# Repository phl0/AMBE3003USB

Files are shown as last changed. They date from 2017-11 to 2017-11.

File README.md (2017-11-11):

# AMBE3003USB

This is a homebrew evaluation board for AMBE-3000 and AMBE-3003 Chips. It can be used as a replacement for USB-3003 devices to work as a transcoder for [XLX](https://github.com/LX3JL/xlxd) reflectors. This board is supported by the AMBEd daemon from version 1.2 onwards.

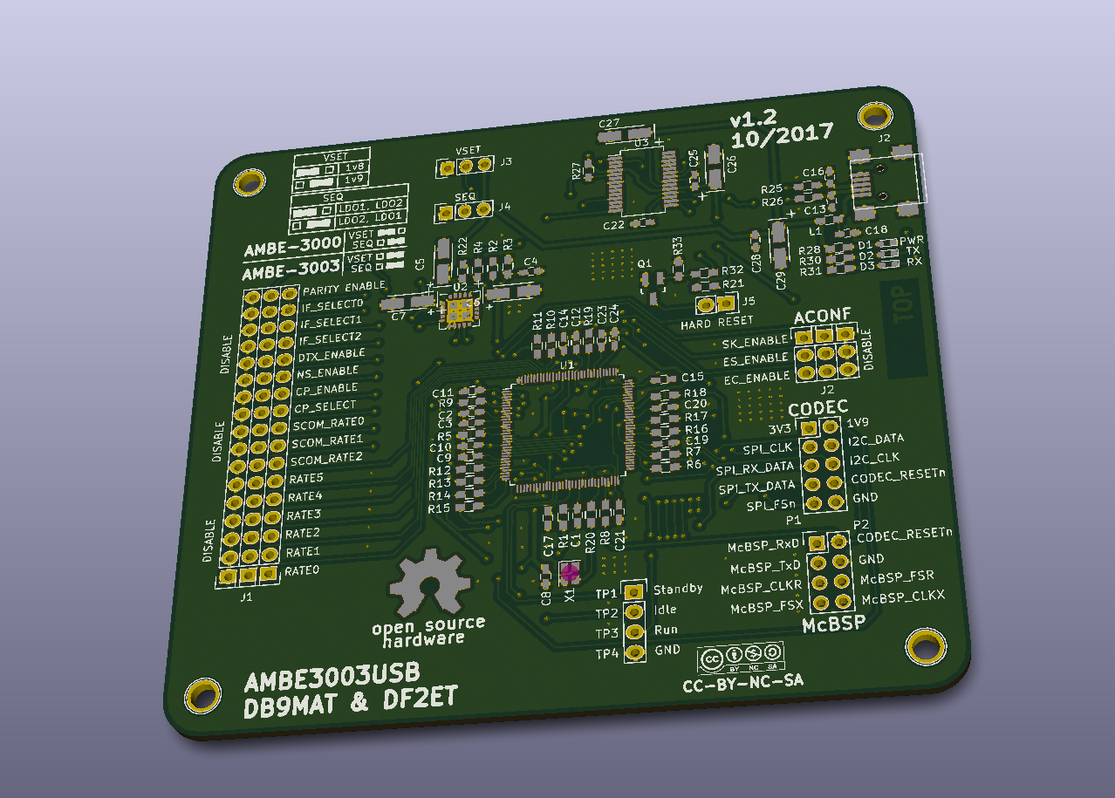
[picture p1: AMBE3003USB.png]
PCB


## Version 1.0

This is the initial version. Apparently it has two errors: The power supply is faulty due to R42 being to small in value. Bypassing the resistor works basically. The 1v9 rail draws to much power resulting in U5 running hot. 
The second issue is that this revision does not support hardware reset of the AMBE-3003 CPU. Soft reset does not work 100% reliably. In this case only un- and re-plugging the device works.

This is the link to the [Mouser project](https://www.mouser.com/ProjectManager/ProjectDetail.aspx?AccessID=42f49e97ec) shopping cart.

**This version is not recommended for (re-)production!**

## Version 1.1

The power supply has been redesigned. An additional transistor has been added to allow for a hardware reset using the DTR pin of the FT-232RL. This needs code changes in the XLX code. Additionally there have been added some more pins to the pin header that allow for configuring parity for AMBE-3000 chips by jumper.

Testing this version revealed an issue with missing pull-up resistor on the PWREN signal. That results in the voltage regulator not beeing activated. Quick fix is to add a 10k SMD resistor from bottom pin of R4 to anode of C5 (5v0). This is going to be fixed in revision 1.2.

This is the link to the [Mouser project](https://www.mouser.com/ProjectManager/ProjectDetail.aspx?AccessID=05fa8acc46) shopping cart.

**This version is not recommended for (re-)production!**

## Version 1.2

A 10k resistor (R22) was added to the schematics and board layout. 

This is the link to the [Mouser project](https://www.mouser.com/ProjectManager/ProjectDetail.aspx?AccessID=9071144aec) shopping cart.

**This version has not been tested yet. Use at your own risk.**

# Usage

## Flashing FT232

After building the board you have to flash the onboard FT-232 USB converter. The AMBEd expects to find this device with product ID "DF2ET-3003". The product ID can be flashed with the original FTprog by FTDI or using [ft232r_prog](http://rtr.ca/ft232r/) (command is ./ft232r_prog --product "DF2ET-3003").

## Setting Jumpers

* VSET has to be set to 1v9 for an AMBE-3003 chip (1v8 for AMBE-3000).
* SEQ needs to be LDO2, LDO1
* PARITY_ENABLE is ignored by an AMBE-3003 (disabled for AMBE-3000)
* IF_SELECT has to be set to UART (being IF_SELECT0 and IF_SELECT2 enabled, IF_SELECT1 disabled)
* DTX_ENABLE disabled
* NS_ENABLE disabled
* CP_ENABLE disabled
* CP_SELECT disabled
* SCOM_RATE has to be configured for 921,600 bit/s (which is SCOM_RATE0 and SCOM_RATE2 enabled, SCOM_RATE1 disabled)
* RATE settings are ignored in UART mode. No need for jumpers though

* HARD_RESET can be enabled by setting J5. Otherwise the code relies on a software reset only

* SK_ENABLE not used by AMBE-3003
* ES_ENABLE not used by AMBE-3003
* EC_ENABLE not used by AMBE-3003

## Drivers

If using in combination with XLX/AMBEd make sure that the operating system does not load the commonly used ftdi_sio kernel module to provide an USB-serial interface. The AMBEd makes use of the ft2xx direct access driver by FTDI with does not work if the kernel module is loaded. Hints on how this can be accomplished can be found in my [Blog](https://www.florian-wolters.de/blog/2017/08/18/excluding-ft-232-from-ftdi-sio-driver/).

# Contributors

This is the list of contributors. Thank you for your additions:

* Mathis, DB9MAT

# License

This project is released under the Creative Commons Attribution-NonCommercial-ShareAlike 3.0 (CC-BY-NC-SA 3.0, https://creativecommons.org/licenses/by-nc-sa/3.0/) license. You may edit and share it as you like, as long as credit is given and the license is not changed. You can build as many boards for you and your friends as you like and you can even sell it to them to cover your costs, **however it is strictly forbidden to turn this into a commercial product! You are not allowed to build and sell these boards for profit!**

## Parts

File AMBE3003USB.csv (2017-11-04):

Refs | Value | Footprint | QTY | MFR | MPN | SPR | SPN
C28;C25;C23;C20;C17;C14;C11;C9;C24;C21;C19;C15;C12;C10;C22 | 100n | Capacitors_SMD:C_0603_HandSoldering | 15 | Murata Electronics | GRM188R70J104KA01D | Mouser | 81-GRM188R70J104KA1D
C18;C1;C8;C4 | 10n | Capacitors_SMD:C_0603_HandSoldering | 4 | Murata Electronics | GRM188R70J103KA01D | Mouser | 81-GRM188R70J103KA1D
C3;C2 | 10u | Capacitors_SMD:C_0603_HandSoldering | 2 | Murata Electronics | GRM188R60J106ME47D | Mouser | 81-GRM188R60J106ME47
C13;C16 | 47p | Capacitors_SMD:C_0603_HandSoldering | 2 | AVX | 06036A470JAT2A | Mouser | 581-06036A470JAT2A
C5;C7;C6 | 10u | Capacitors_Tantalum_SMD:TantalC_SizeA_EIA-3216_HandSoldering | 3 | KEMET | T495A106K016ATE1K7 | Mouser | 80-T495A106K016AT
C26;C27 | 1u | Capacitors_Tantalum_SMD:TantalC_SizeA_EIA-3216_HandSoldering | 2 | KEMET | T495A105K020ATE3K0 | Mouser | 80-T495A105K20ATE3K0
C29 | 4u7 | Capacitors_Tantalum_SMD:TantalC_SizeA_EIA-3216_HandSoldering | 1 | KEMET | T495A475K020ATE1K8 | Mouser | 80-T495A475K20ATE1K8
J2 | USB_OTG | Connect:USB_Mini-B | 1 | Molex | 67503-1020 | Mouser | 538-67503-1020
U2 | TPS75005RGW_wPin21 | Housings_DFN_QFN:QFN-20-1EP_5x5mm_Pitch0.65mm | 1 | Texas Instruments | TPS75005RGWT | Mouser | 595-TPS75005RGWT
U1 | AMBE3003 | Housings_QFP:TQFP-128_14x14mm_Pitch0.4mm | 1 | DVSI | AMBE-3003
U3 | FT232RL | Housings_SSOP:SSOP-28_5.3x10.2mm_Pitch0.65mm | 1 | FTDI | FT232RL-REEL | Mouser | 895-FT232RL
L1 | 100MHz | Inductors_SMD:L_0603_HandSoldering | 1 | Murata Electronics | BLM18KG471BH1D | Mouser | 81-BLM18KG471BH1D
D1 | green | LEDs:LED_0603 | 1 | Wurth Electronics | 150060VS75000 | Mouser | 710-150060VS75000
D3 | red | LEDs:LED_0603 | 1 | Wurth Electronics | 150060SS75000 | Mouser | 710-150060SS75000
D2 | yellow | LEDs:LED_0603 | 1 | Wurth Electronics | 150060YS75000 | Mouser | 710-150060YS75000
X1 | 29.4912 | Oscillators:Oscillator_SMD_SeikoEpson_SG210-4pin_2.5x2.0mm | 1 | Epson Timing | SG-210STF 29.4912ML3 | Mouser | 732-SG210STF29.491L3
P5 | HARD RESET | Pin_Headers:Pin_Header_Straight_1x02 | 1 | Harwin | M20-9990246 | Mouser | 855-M20-9990246
P7 | 3v3 | Pin_Headers:Pin_Header_Straight_1x03 | 1 | Harwin | M20-9990346 | Mouser | 855-M20-9990346
P8 | ACONF | Pin_Headers:Pin_Header_Straight_1x03 | 1 | Harwin | M20-9990346 | Mouser | 855-M20-9990346
P9 | GND | Pin_Headers:Pin_Header_Straight_1x03 | 1 | Harwin | M20-9990346 | Mouser | 855-M20-9990346
P6 | SEQ | Pin_Headers:Pin_Header_Straight_1x03 | 1 | Harwin | M20-9990346 | Mouser | 855-M20-9990346
P4 | VSET | Pin_Headers:Pin_Header_Straight_1x03 | 1 | Harwin | M20-9990346 | Mouser | 855-M20-9990346
TP1 | Testpoints | Pin_Headers:Pin_Header_Straight_1x04 | 1 | Harwin | M20-9990446 | Mouser | 855-M20-9990446
P3 | 3v3 | Pin_Headers:Pin_Header_Straight_1x17 | 1 | Harwin | M20-9991746 | Mouser | 855-M20-9991746
P2 | Config | Pin_Headers:Pin_Header_Straight_1x17 | 1 | Harwin | M20-9991746 | Mouser | 855-M20-9991746
P1 | GND | Pin_Headers:Pin_Header_Straight_1x17 | 1 | Harwin | M20-9991746 | Mouser | 855-M20-9991746
J1 | McBSP | Pin_Headers:Pin_Header_Straight_2x04 | 1 | Harwin | M20-9980445 | Mouser | 855-M20-9980445
J4 | CODEC | Pin_Headers:Pin_Header_Straight_2x05 | 1 | Harwin | M20-9980545 | Mouser | 855-M20-9980545
R12;R13;R14;R15;R16;R17;R18;R6;R7;R8;R9;R10;R11;R19 | 0R | Resistors_SMD:R_0603_HandSoldering | 14 | Yageo | RC0603FR-070RL | Mouser | 603-RC0603FR-070RL
R21;R3;R33;R22 | 10k | Resistors_SMD:R_0603_HandSoldering | 4 | Yageo | RC0603FR-0710KL | Mouser | 603-RC0603FR-0710KL
R32 | 1k | Resistors_SMD:R_0603_HandSoldering | 1 | Yageo | RC0603FR-071KL | Mouser | 603-RC0603FR-071KL
R5;R27;R4 | 24k | Resistors_SMD:R_0603_HandSoldering | 3 | Yageo | RC0603FR-0724KL | Mouser | 603-RC0603FR-0724KL
R25;R26 | 27 | Resistors_SMD:R_0603_HandSoldering | 2 | Yageo | RC0603FR-0727RL | Mouser | 603-RC0603FR-0727RL
R30;R31;R28 | 270 | Resistors_SMD:R_0603_HandSoldering | 3 | Yageo | RC0603FR-07270RL | Mouser | 603-RC0603FR-07270RL
R2 | 3k74 | Resistors_SMD:R_0603_HandSoldering | 1 | Yageo | RC0603FR-073K74L | Mouser | 603-RC0603FR-073K74L
R1;R20 | 5.1 | Resistors_SMD:R_0603_HandSoldering | 2 | Yageo | RC0603FR-075R11L | Mouser | 603-RC0603FR-075R11L
Q1 | BC847 | TO_SOT_Packages_SMD:SOT-23_Handsoldering | 1 | ON Semiconductor | BC847BLT1G | Mouser | 863-BC847BLT1G

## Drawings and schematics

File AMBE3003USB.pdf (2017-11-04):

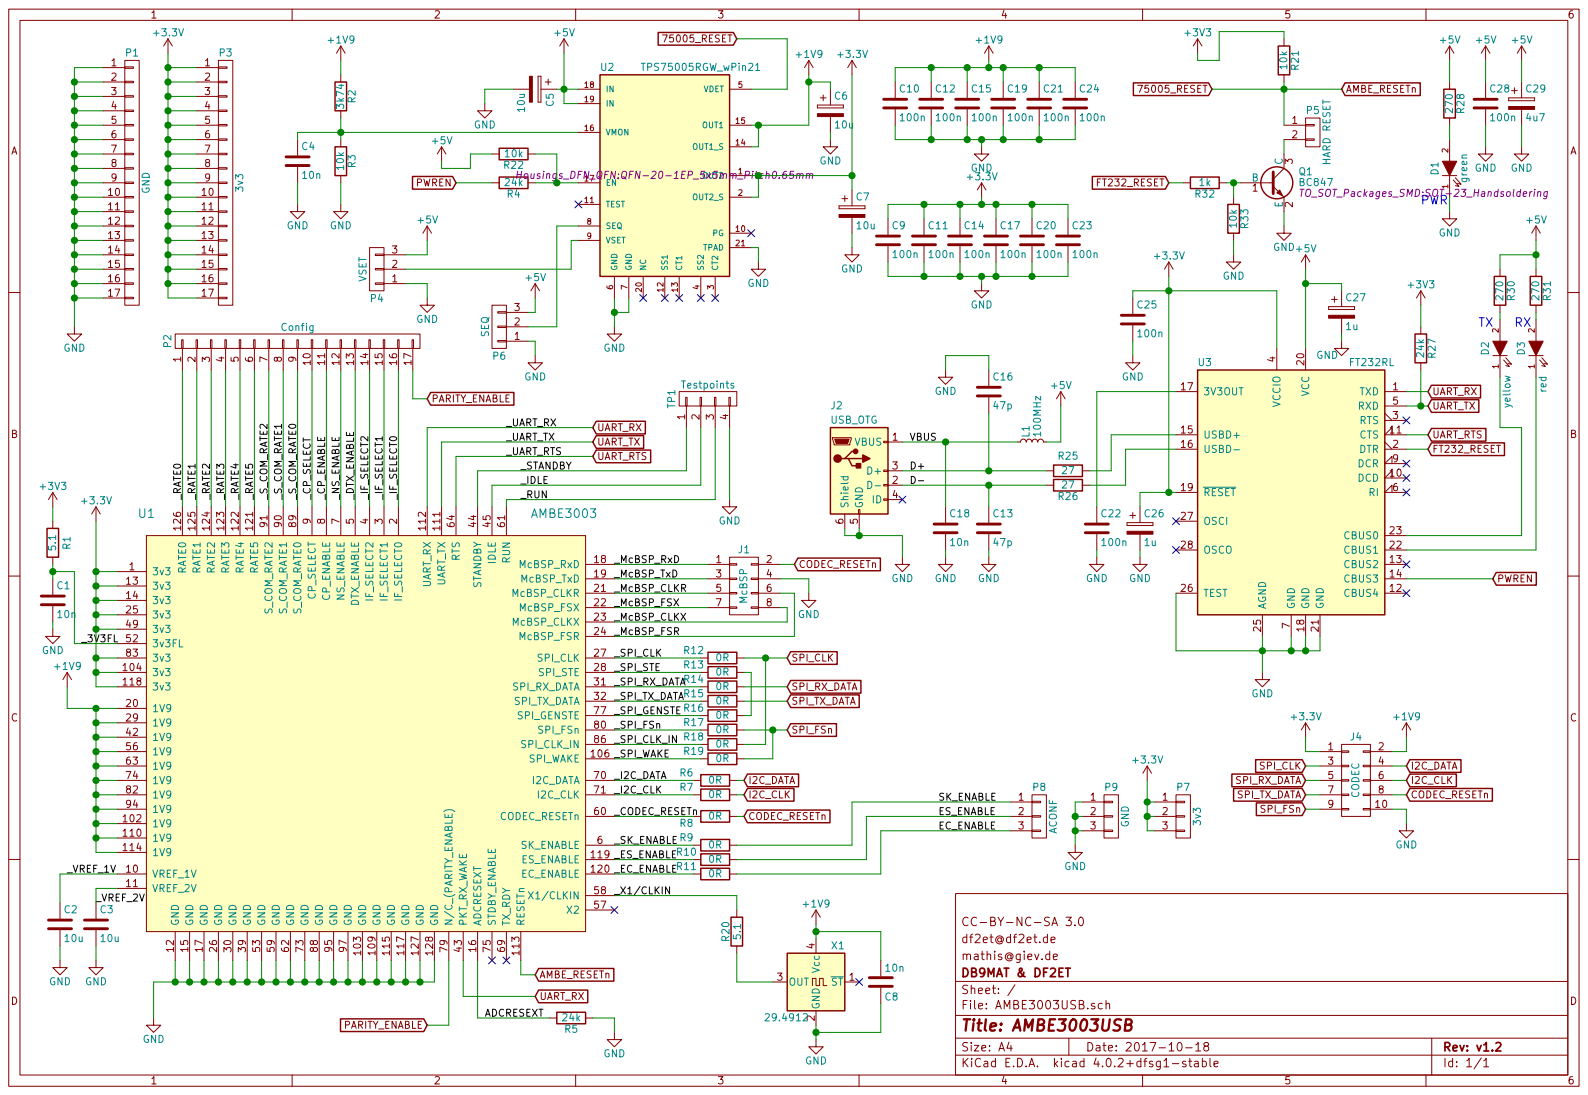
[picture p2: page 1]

7 SEQ 8 VSET 9 PG 10 NC 20 TEST 11 TPAD 21 SS1 12 CT1 13 OUT1_S 14 OUT1 15 VMON 16 EN 17

10
11
12
13
14

7 DCR 9 DCD 10 VCC 20 CTS 11 GND 21 CBUS4 12 CBUS1 22 CBUS2 13 CBUS0 23 CBUS3 14 USBD+ 15 AGND 25 USBD- 16 TEST 26

CODEC_RESETn
df2et@df2et.de CC-BY-NC-SA 3.0 GND

_McBSP_TxD 3 | 4
_McBSP_CLKR 5 | 6

File: AMBE3003USB.sch Sheet: / DB9MAT & DF2ET mathis@giev.de

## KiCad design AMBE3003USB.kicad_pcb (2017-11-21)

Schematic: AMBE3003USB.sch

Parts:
C1, C4, C8, C18: 10n; C_0603_HandSoldering; MPN GRM188R70J103KA01D
C2, C3: 10u; C_0603_HandSoldering; MPN GRM188R60J106ME47D
C5, C6, C7: 10u; TantalC_SizeA_EIA-3216_HandSoldering; MPN T495A106K016ATE1K7
C9, C10, C11, C12, C14, C15, C17, C19, C20, C21, C22, C23, C24, C25, C28: 100n; C_0603_HandSoldering; MPN GRM188R70J104KA01D
C13, C16: 47p; C_0603_HandSoldering; MPN 06036A470JAT2A
C26, C27: 1u; TantalC_SizeA_EIA-3216_HandSoldering; MPN T495A105K020ATE3K0
C29: 4u7; TantalC_SizeA_EIA-3216_HandSoldering; MPN T495A475K020ATE1K8
D1: green; LED_0603; MPN 150060VS75000
D2: yellow; LED_0603; MPN 150060YS75000
D3: red; LED_0603; MPN 150060SS75000
J1: McBSP; Pin_Header_Straight_2x04; MPN M20-9980445
J2: USB_OTG; USB_Mini-B; MPN 67503-1020
J4: CODEC; Pin_Header_Straight_2x05; MPN M20-9980545
L1: 100MHz; L_0603_HandSoldering; MPN BLM18KG471BH1D
P1: GND; Pin_Header_Straight_1x17; MPN M20-9991746
P2: Config; Pin_Header_Straight_1x17; MPN M20-9991746
P3: 3v3; Pin_Header_Straight_1x17; MPN M20-9991746
P4: VSET; Pin_Header_Straight_1x03; MPN M20-9990346
P5: HARD RESET; Pin_Header_Straight_1x02; MPN M20-9990246
P6: SEQ; Pin_Header_Straight_1x03; MPN M20-9990346
P7: 3v3; Pin_Header_Straight_1x03; MPN M20-9990346
P8: ACONF; Pin_Header_Straight_1x03; MPN M20-9990346
P9: GND; Pin_Header_Straight_1x03; MPN M20-9990346
Q1: BC847; SOT-23_Handsoldering; MPN BC847BLT1G
R1, R20: 5.1; R_0603_HandSoldering; MPN RC0603FR-075R11L
R2: 3k74; R_0603_HandSoldering; MPN RC0603FR-073K74L
R3, R21, R22, R33: 10k; R_0603_HandSoldering; MPN RC0603FR-0710KL
R4, R5, R27: 24k; R_0603_HandSoldering; MPN RC0603FR-0724KL
R6, R7, R8, R9, R10, R11, R12, R13, R14, R15, R16, R17, R18, R19: 0R; R_0603_HandSoldering; MPN RC0603FR-070RL
R25, R26: 27; R_0603_HandSoldering; MPN RC0603FR-0727RL
R28, R30, R31: 270; R_0603_HandSoldering; MPN RC0603FR-07270RL
R32: 1k; R_0603_HandSoldering; MPN RC0603FR-071KL
TP1: Testpoints; Pin_Header_Straight_1x04; MPN M20-9990446
U1: AMBE3003; TQFP-128_14x14mm_Pitch0.4mm; MPN AMBE-3003
U2: TPS75005RGW_wPin21; QFN-20-1EP_5x5mm_Pitch0.65mm; MPN TPS75005RGWT
U3: FT232RL; SSOP-28_5.3x10.2mm_Pitch0.65mm; MPN FT232RL-REEL
X1: 29.4912; Oscillator_SMD_SeikoEpson_SG210-4pin_2.5x2.0mm; MPN SG-210STF 29.4912ML3

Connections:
75005_RESET: P5.1, R21.2, U1.113 (RESETn), U2.5
+1V9: C6.1, C8.2, C10.1, C12.1, C15.1, C19.1, C21.1, C24.1, J4.2, R2.1, U1.20 (1V9), U1.29 (1V9), U1.42 (1V9), U1.56 (1V9), U1.63 (1V9), U1.74 (1V9), U1.82 (1V9), U1.94 (1V9), U1.102 (1V9), U1.110 (1V9), U1.114 (1V9), U2.14, U2.15, X1.4 (Vcc)
+5V: C5.1, C27.1, C28.1, C29.1, L1.2, P4.3, P6.3, R22.2, R28.1, R30.1, R31.1, U2.18, U2.19, U3.20 (VCC)
/ADCRESEXT: R5.2, U1.16 (ADCRESEXT)
/D+: C16.2, J2.3 (D+), R25.2
/D-: C13.1, J2.2 (D-), R26.2
/EC_ENABLE: P8.3, R11.1
/ES_ENABLE: P8.2, R10.1
/SK_ENABLE: P8.1, R9.1
/VBUS: C18.1, J2.1 (VBUS), L1.1
/_3V3FL: C1.1, R1.2, U1.52 (3v3FL)
/_CODEC_RESETn: R8.2, U1.60 (CODEC_RESETn)
/_CP_ENABLE: P2.11, U1.8 (CP_ENABLE)
/_CP_SELECT: P2.10, U1.9 (CP_SELECT)
/_DTX_ENABLE: P2.13, U1.5 (DTX_ENABLE)
/_EC_ENABLE: R11.2, U1.120 (EC_ENABLE)
/_ES_ENABLE: R10.2, U1.119 (ES_ENABLE)
/_I2C_CLK: R7.2, U1.71 (I2C_CLK)
/_I2C_DATA: R6.2, U1.70 (I2C_DATA)
/_IDLE: TP1.2, U1.45 (IDLE)
/_IF_SELECT0: P2.16, U1.2 (IF_SELECT0)
/_IF_SELECT1: P2.15, U1.3 (IF_SELECT1)
/_IF_SELECT2: P2.14, U1.4 (IF_SELECT2)
/_McBSP_CLKR: J1.5, U1.21 (McBSP_CLKR)
/_McBSP_CLKX: J1.8, U1.23 (McBSP_CLKX)
/_McBSP_FSR: J1.6, U1.24 (McBSP_FSR)
/_McBSP_FSX: J1.7, U1.22 (McBSP_FSX)
/_McBSP_RxD: J1.1, U1.18 (McBSP_RxD)
/_McBSP_TxD: J1.3, U1.19 (McBSP_TxD)
/_NS_ENABLE: P2.12, U1.7 (NS_ENABLE)
/_RATE0: P2.1, U1.126 (RATE0)
/_RATE1: P2.2, U1.125 (RATE1)
/_RATE2: P2.3, U1.124 (RATE2)
/_RATE3: P2.4, U1.123 (RATE3)
/_RATE4: P2.5, U1.122 (RATE4)
/_RATE5: P2.6, U1.121 (RATE5)
/_RUN: TP1.3, U1.61 (RUN)
/_SK_ENABLE: R9.2, U1.6 (SK_ENABLE)
/_SPI_CLK: R12.2, U1.27 (SPI_CLK)
/_SPI_CLK_IN: R18.2, U1.86 (SPI_CLK_IN)
/_SPI_FSn: R17.2, U1.80 (SPI_FSn)
/_SPI_GENSTE: R16.2, U1.77 (SPI_GENSTE)
/_SPI_RX_DATA: R14.2, U1.31 (SPI_RX_DATA)
/_SPI_STE: R13.2, U1.28 (SPI_STE)
/_SPI_TX_DATA: R15.2, U1.32 (SPI_TX_DATA)
/_SPI_WAKE: R19.2, U1.106 (SPI_WAKE)
/_STANDBY: TP1.1, U1.44 (STANDBY)
/_S_COM_RATE0: P2.9, U1.89 (S_COM_RATE0)
/_S_COM_RATE1: P2.8, U1.90 (S_COM_RATE1)
/_S_COM_RATE2: P2.7, U1.91 (S_COM_RATE2)
/_VREF_1V: C2.1, U1.10 (VREF_1V)
/_VREF_2V: C3.1, U1.11 (VREF_2V)
/_X1/CLKIN: R20.2, U1.58 (X1/CLKIN)
CODEC_RESETn: J1.2, J4.8, R8.1
FT232_RESET: R32.2, U3.2 (DTR)
GND: C1.2, C2.2, C3.2, C4.2, C5.2, C6.2, C7.2, C8.1, C9.2, C10.2, C11.2, C12.2, C13.2, C14.2, C15.2, C16.1, C17.2, C18.2, C19.2, C20.2, C21.2, C22.2, C23.2, C24.2, C25.2, C26.2, C27.2, C28.2, C29.2, D1.1 (K), J1.4, J2.5 (GND), J2.6 (Shield), J4.10, P1.1, P1.2, P1.3, P1.4, P1.5, P1.6, P1.7, P1.8, P1.9, P1.10, P1.11, P1.12, P1.13, P1.14, P1.15, P1.16, P1.17, P4.1, P6.1, P9.1, P9.2, P9.3, Q1.2 (E), R3.2, R5.1, R33.2, TP1.4, U1.12 (GND), U1.15 (GND), U1.17 (GND), U1.26 (GND), U1.30 (GND), U1.39 (GND), U1.48 (PPT_ACK), U1.53 (GND), U1.59 (GND), U1.62 (GND), U1.73 (GND), U1.88 (GND), U1.95 (GND), U1.97 (GND), U1.103 (GND), U1.109 (GND), U1.115 (GND), U1.117 (GND), U1.127 (GND), U1.128 (GND), U2.6, U2.7, U2.21, U3.7 (GND), U3.18 (GND), U3.21 (GND), U3.25 (AGND), U3.26 (TEST), X1.2 (GND)
I2C_CLK: J4.6, R7.1
I2C_DATA: J4.4, R6.1
unnamed: C4.1, R2.2, R3.1, U2.16
unnamed: C22.1, U3.17 (3V3OUT)
unnamed: D1.2 (A), R28.2
unnamed: D2.1 (K), U3.23 (CBUS0)
unnamed: D2.2 (A), R30.2
unnamed: D3.1 (K), U3.22 (CBUS1)
unnamed: D3.2 (A), R31.2
unnamed: P4.2, U2.9
unnamed: P5.2, Q1.3 (C)
unnamed: P6.2, U2.8
unnamed: Q1.1 (B), R32.1, R33.1
unnamed: R13.1, R16.1
unnamed: R20.1, X1.3 (OUT)
unnamed: R4.1, R22.1, U2.17
unnamed: R25.1, U3.15 (USBD+)
unnamed: R26.1, U3.16 (USBD-)
PARITY_ENABLE: P2.17, U1.79 (N/C)
PWREN: R4.2, U3.14 (CBUS3)
SPI_CLK: J4.3, R12.1, R18.1
SPI_FSn: J4.9, R17.1, R19.1
SPI_RX_DATA: J4.5, R14.1
SPI_TX_DATA: J4.7, R15.1
UART_RTS: U1.64 (RTS), U3.11 (CTS)
UART_RX: U1.43 (PKT_RX_WAKE), U1.112 (UART_RX), U3.1 (TXD)
UART_TX: R27.2, U1.111 (UART_TX), U3.5 (RXD)

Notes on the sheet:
PWR

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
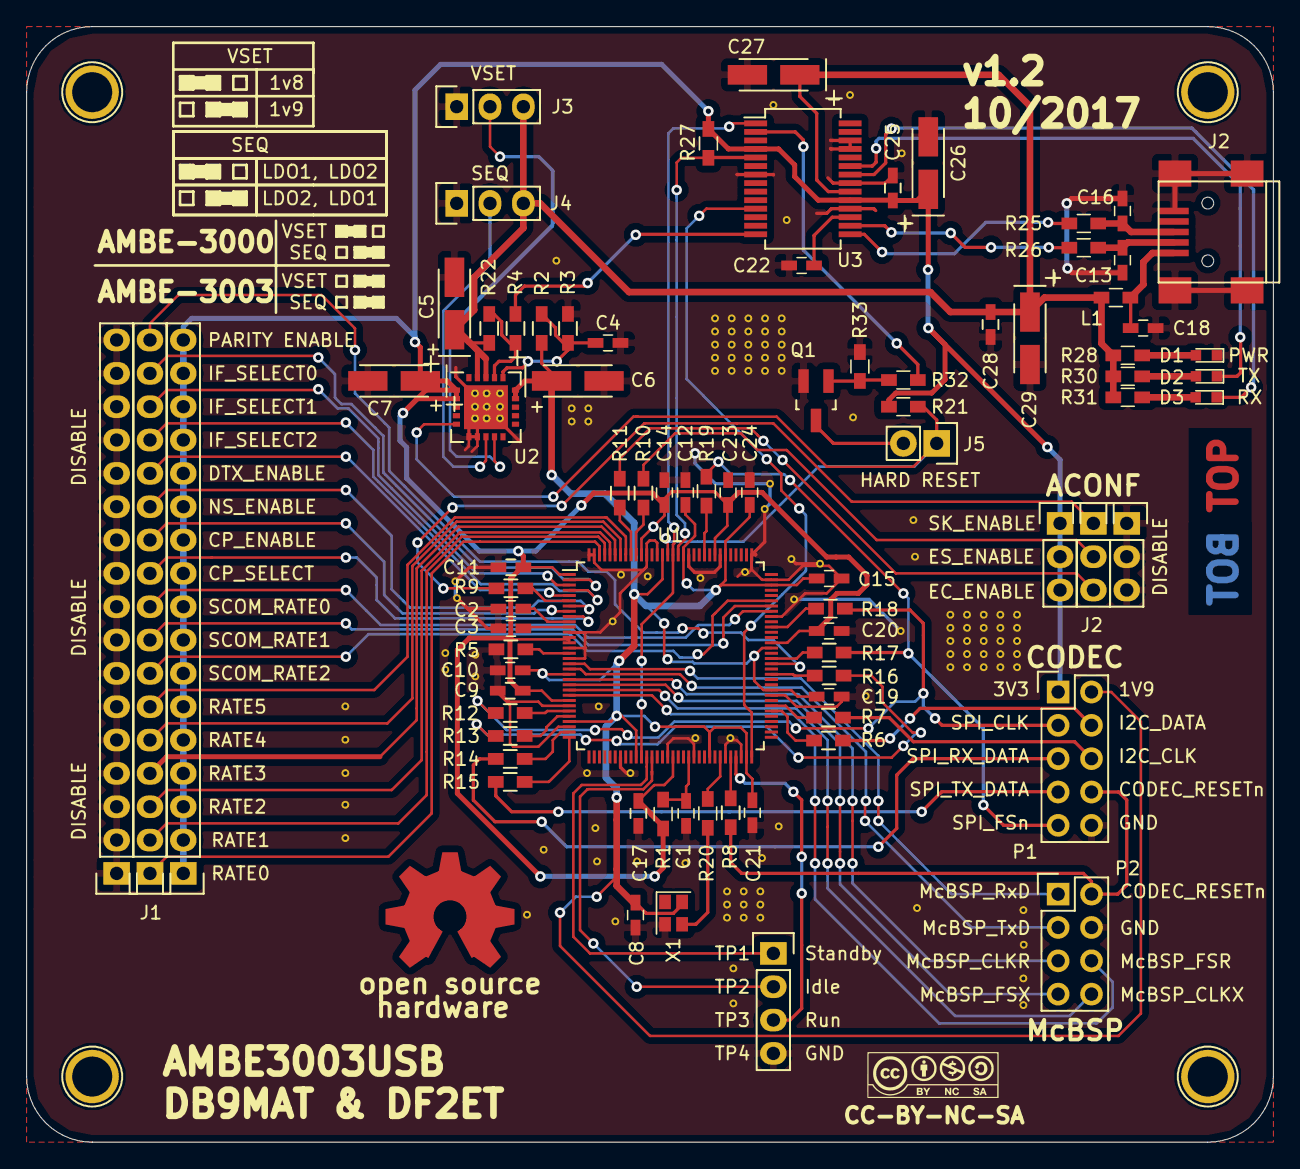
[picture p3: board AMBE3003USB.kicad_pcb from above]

Board: 2 copper layers, 95.0 x 85.0 mm, 82 parts (0 on the bottom side), 84 nets.

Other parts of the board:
OSHW_COPPER_10MM: VAL**; OSHW_COPPER_10MM

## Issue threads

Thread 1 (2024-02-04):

Sourcing of AMBE3003 parts

m1geo, 2024-02-04:
Hi gents. Where did you obtain AMBE 3003 parts from in hobby quantities? Thanks, George, M1GEO.

m1geo, 2024-02-04:
Ignore that, I found that they do a 6-piece order minimum for one time. Details on [dvsinc price list](https://www.dvsinc.com/products/price.shtml).

phl0, 2024-02-05:
> Ignore that, I found that they do a 6-piece order minimum for one time. Details on [dvsinc price list](https://www.dvsinc.com/products/price.shtml).

Thats exactly what I did. Apparently you can only order that 6 pieces ones. Thats why I only did 3 PCBs :(

dave31418, 2024-02-05:
When I ordered some of the AMBE3000's , DVSI failed to let me know subsequent orders would need to be for larger quantities.   Not knowing this I developed a board and I sold a few interfaces but since I only started with 10 they didn't go far.   Every month I get a few inquiries about the next build.    I'm considering ordering the minimum quantity just so I can do a build.    This becomes an easier decision if some of you guys want a few.   I would be happy to share at cost plus shipping.    I don't know but that may violate their terms of service if I distribute them.   I will look into this.    ( I am speaking AMBE3000 not the 3003 )

m1geo, 2024-02-05:
I could be interested in that; **3x**AMBE3000 vs **1x**AMBE3003 is cheaper, and I don't care about size at all as these are for a VHF WebSDR (openwebrx). In fact, **3x**AMBE3000 is probably better, in some regards. If you're seriously considering this, drop me an [email](http://www.george-smart.co.uk/cgi-bin/socialmedia.cgi/email).

Closed 2024-02-04.

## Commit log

2017-05-17 First shot
    [AMBE3003USB.kicad_pcb, AMBE3003USB.sch]
2017-05-17 Add meta information and resolve some errors
    [AMBE3003USB.sch]
2017-05-17 Add PWR LED and some labels
    [AMBE3003USB.sch]
2017-05-17 Add voltage regulators for 1v9 and 3v3
    [AMBE3003USB.sch]
2017-05-17 Add AMBE3003 symbol
    [AMBE3003USB.sch]
2017-05-17 Add AMBE3003 chip to schematic
    [AMBE3003USB.sch]
2017-05-17 Add jumpers for AMBE3003 and some refactoring
    [AMBE3003USB.sch]
2017-05-18 Add Rs and Cs to USB connection
    [AMBE3003USB.sch]
2017-05-18 Refactor USB connection and drop 3v3 regulator
    [AMBE3003USB.sch]
2017-05-23 Add reset circuit
    [AMBE3003USB.sch]
2017-05-24 Added support for AMBE3000; Added 3v3 Regulator; Added Codec Connections
    [AMBE3003USB.sch]
2017-05-24 Annotate PCB
    [AMBE3003USB.sch]
2017-05-24 Refactoring and re-configured some pins
    [AMBE3003USB.sch]
2017-05-26 Re-organized Codec Connector
    [AMBE3003USB.sch]
2017-05-26 Added footprints
    [AMBE3003USB.sch]
2017-05-26 Initial PCB
2017-05-26 PCB Work In Progress
    [AMBE3003USB.kicad_pcb]
2017-05-26 Align capacitor values
    [AMBE3003USB.sch]
2017-05-26 Change Cap footprint to case A
    [AMBE3003USB.kicad_pcb, AMBE3003USB.sch]
2017-05-26 Component Placement Done
    [AMBE3003USB.kicad_pcb, AMBE3003USB.sch]
2017-06-07 Routed some signal pins, 1v9 and 3v3
    [AMBE3003USB.kicad_pcb]
2017-06-08 Add outline
    [AMBE3003USB.kicad_pcb]
2017-06-08 Make outline a little thinner
    [AMBE3003USB.kicad_pcb]
2017-06-08 Add GND zones
    [AMBE3003USB.kicad_pcb]
2017-06-08 Refactor all unconnected pins
    [AMBE3003USB.kicad_pcb]
2017-06-08 Reorder some descriptors
    [AMBE3003USB.kicad_pcb]
2017-06-08 Rounded corners, added descriptors
    [AMBE3003USB.kicad_pcb, AMBE3003USB.sch]
2017-06-08 Add OSHW logo and realign jumpers
    [AMBE3003USB.kicad_pcb]
2017-06-08 Added nice net names / labels
    [AMBE3003USB.kicad_pcb, AMBE3003USB.sch]
2017-06-08 Add some more labels
    [AMBE3003USB.kicad_pcb, AMBE3003USB.sch]
2017-06-09 Refactor schematic (moved C24)
    [AMBE3003USB.kicad_pcb, AMBE3003USB.sch]
2017-06-09 Add LED colors and descriptors to board
    [AMBE3003USB.kicad_pcb, AMBE3003USB.sch]
2017-06-09 Change footprint of USB connector
    [AMBE3003USB.kicad_pcb, AMBE3003USB.sch]
2017-06-09 Add BOM for resistors
    [AMBE3003USB.sch]
2017-06-09 Add BOM for 5.1 resistor
    [AMBE3003USB.sch]
2017-06-09 Add BOM for ICs
    [AMBE3003USB.sch]
2017-06-09 Add BOM for pin headers
    [AMBE3003USB.sch]
2017-06-09 Add BOM for FT232RL
    [AMBE3003USB.sch]
2017-06-09 BOMming the EPSON XO
    [AMBE3003USB.sch]
2017-06-09 Add BOM for Cs with n capacitance
    [AMBE3003USB.sch]
2017-06-09 Change units for caps to make BOM work
    [AMBE3003USB.kicad_pcb, AMBE3003USB.sch]
2017-06-09 Add BOMs for capacitors
    [AMBE3003USB.sch]
2017-06-09 Add BOM and footprint for AMBE3003
    [AMBE3003USB.sch]
2017-06-10 Add BOM info for AMBE3003
2017-06-10 Add a picture and BOM as csv
    [AMBE3003USB.csv]
2017-06-12 Re-add mounting holes
    [AMBE3003USB.kicad_pcb]
2017-06-17 Better reverse RX/TX LEDs
    [AMBE3003USB.kicad_pcb, AMBE3003USB.sch]
2017-06-17 Re-route the PCB layout
    [AMBE3003USB.kicad_pcb, AMBE3003USB.sch]
2017-06-17 Add Testpad for GND
    [AMBE3003USB.kicad_pcb, AMBE3003USB.sch]
2017-06-17 Re-add OSH logo and TOP/BOT icons
    [AMBE3003USB.kicad_pcb]
2017-06-17 Refactor schematic a little
    [AMBE3003USB.sch]
2017-06-18 Increase clearance to 0.3mm and refactor whole PCB
    [AMBE3003USB.kicad_pcb]
2017-06-18 Refactor PCB with 0.3mm clearance
    [AMBE3003USB.kicad_pcb]
2017-06-18 Refacor PCB with smaller clearance
    [AMBE3003USB.kicad_pcb]
2017-06-19 USB Shield to GND; Testpoint Descriptions on PCB
    [AMBE3003USB.kicad_pcb]
2017-06-19 Update BOM for Mouser
    [AMBE3003USB.csv, AMBE3003USB.sch]
2017-06-25 Align to MultiCB doc
    [AMBE3003USB.kicad_pcb]
2017-08-20 Add PDF for schematics
2017-10-18 Redesign power supply (schematic only)
    [AMBE3003USB.kicad_pcb, AMBE3003USB.sch]
2017-10-18 Wire DTR to AMBE Reset
    [AMBE3003USB.sch]
2017-10-18 Refactor reset path
    [AMBE3003USB.kicad_pcb, AMBE3003USB.sch]
2017-10-18 BOM for new power supply
    [AMBE3003USB.csv, AMBE3003USB.kicad_pcb, AMBE3003USB.sch]
2017-10-18 Clear new PCB for redesign
    [AMBE3003USB.kicad_pcb, AMBE3003USB.sch]
2017-10-18 Refactor PCB layout for v1.1
    [AMBE3003USB.kicad_pcb, AMBE3003USB.sch]
2017-10-18 Make BCu GND and add thermal pad for TPS75005
    [AMBE3003USB.kicad_pcb, AMBE3003USB.sch]
2017-10-18 Make PARTIY available on jumper header
    [AMBE3003USB.kicad_pcb, AMBE3003USB.sch]
2017-10-18 Refactor labels
    [AMBE3003USB.kicad_pcb]
2017-10-18 Add nice logo
    [AMBE3003USB.kicad_pcb]
2017-10-18 Correct polarisation for C6 and C7
    [AMBE3003USB.kicad_pcb, AMBE3003USB.sch]
2017-10-18 Add pull-up resistor for PWREN signal
    [AMBE3003USB.kicad_pcb, AMBE3003USB.sch]
2017-10-18 Bump version and date
    [AMBE3003USB.kicad_pcb, AMBE3003USB.sch]
2017-10-18 Add keepout area for top/bottom markers and add author info
    [AMBE3003USB.kicad_pcb, AMBE3003USB.sch]
2017-10-18 Add/update BOM for version 1.2
    [AMBE3003USB.csv, AMBE3003USB.sch, AMBE3003USB.xlsx]
2017-10-18 Add Mouser cart for v1.2 board
2017-10-18 Add CC logo to PCB
    [AMBE3003USB.kicad_pcb]
2017-10-18 Add dimensions for drill holes
    [AMBE3003USB.kicad_pcb]
2017-10-18 Add dimensions for corners
    [AMBE3003USB.kicad_pcb]
2017-10-18 Add jumper setting info to board silkscreen
    [AMBE3003USB.kicad_pcb]
2017-11-21 Move misplaced labels
    [AMBE3003USB.kicad_pcb]
